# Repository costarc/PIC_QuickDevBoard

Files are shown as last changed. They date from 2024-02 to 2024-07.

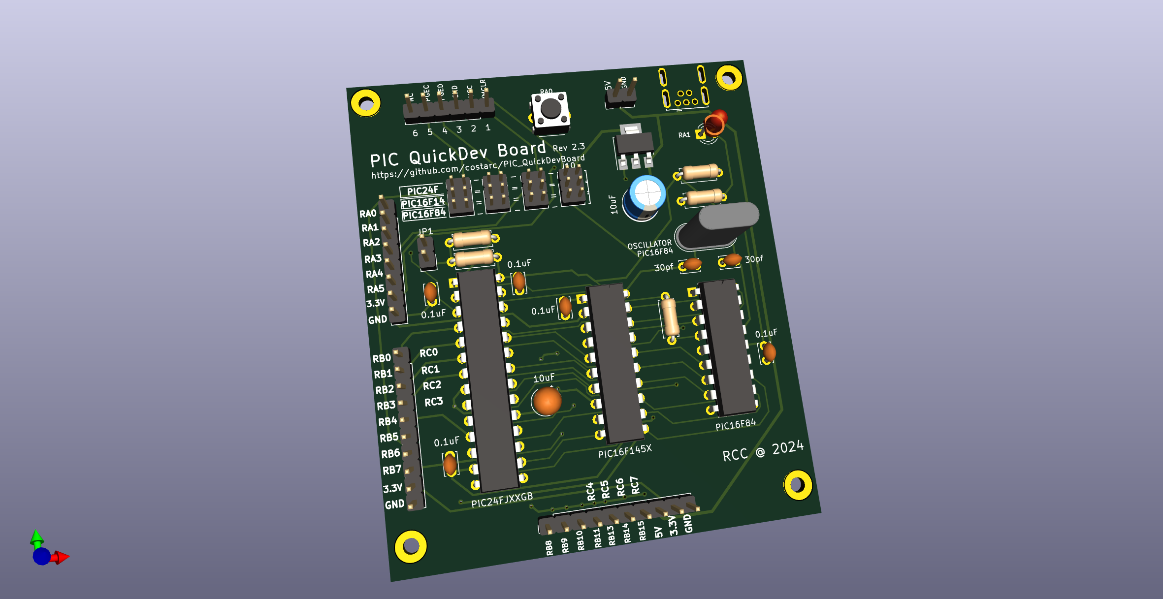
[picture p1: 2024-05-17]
PIC_QuickDevBoard2.png

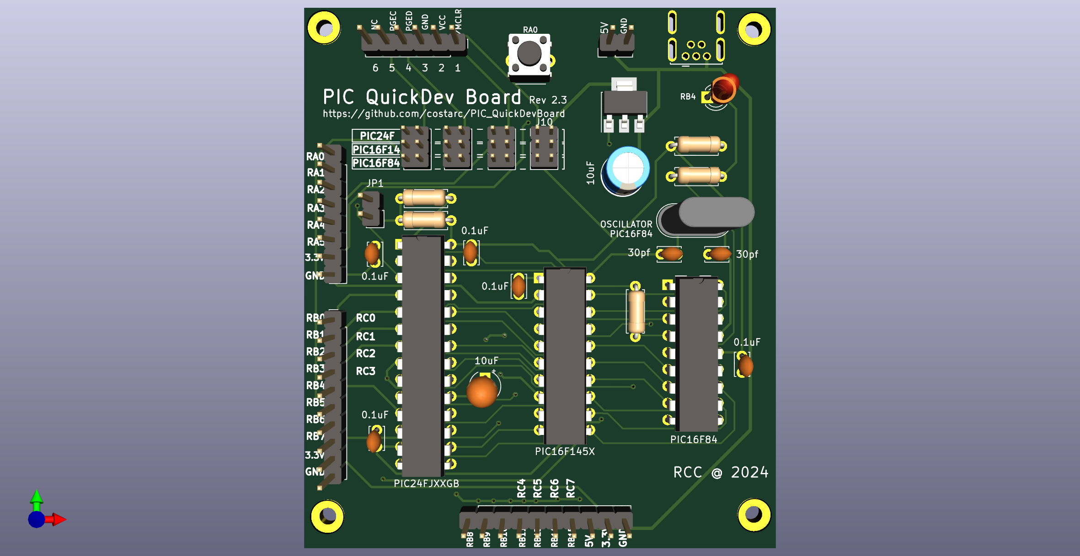
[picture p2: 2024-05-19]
PIC_QuickDevBoard.png

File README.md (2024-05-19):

# PIC_QuickDevBoard
Small and simple PIC16F &amp; PIC24F Development Board with Programming Support for PICKit

Rev 2.3
- Added demo project for all three suported PIC models
- Changed LED to PORT RB4 to be compatible with the 3 PICs supported by the board
- Added missing terminals in the mini-usb custom footprint
- Changed LED resistor from 270R to 470R to avoid led light too bright
- Changed PIC16F84 /MCLR pull-up resistor from 270R to 10K

Rev 2.2
- Adjustments to mini-usb footprint
- Fixed power rails to PC16F145X that was not allowing programming the microcontroller

Rev 2.1
- Updated footprint for USB-Micro to move it to the comopnent side (vcc - gnd was inverted)
- Fix for 5V PICs (16F) with addtion o extra jumpers
- Inverted PICKIT pin header for better alignment (cosmetic change)

Rev 2.0
- Initial production version

Fabrication
-----------
Measures: 70.90 x 81.30

Usage
-----

Power Requirements - PIC16
--------------------------

For correct programing, erasing and verifying the PIC, the external porwer must be provided via the USB connector or the PIN Header.

PIC16 requires 5V - if the PIN Header is used for power, 5V should be provided in this connector.
USB connector will provide the correct 5V for the PIC16.

Power Requirements - PIC24
--------------------------

For correct programing, erasing and verifying the PIC, the external porwer must be provided via the USB connector or the PIN Header.

PIC24 requires 3.3V - if the PIN Header is used for power, 3.3V must be provided in this connector - no conversion is done for voltages provided via this connector.
USB connector will provide the correct 3.3V for the PIC24 via coversion using the LD1117 converter in the board.

Operation * Programming
-----------------------

To develop & program A PIC device, set the three jumpers in position PIC24F, PIC16F14 OR PIC16F84 depending on which device you are being used.

To program the PIC24, remove jumper "Program". Re-insert after programming.

Development Resources
---------------------
All  I/O pins are exposed thorugh the Pin Headers in the board.
Additionaly, a Pushb Button and a LED are available for quick tests and experiments.
Push Button is connected to RA0
LED is connected to RB4

These components can be removed from the board if they are not needed or if they interfere with normal operation of these signals in the Pin Headers.

Default Demonstration Firmware
------------------------------
The demonstration firmware works the same for all models - the LED on RB4 will blink slowly, but if the push button is pressed it will blink faster.

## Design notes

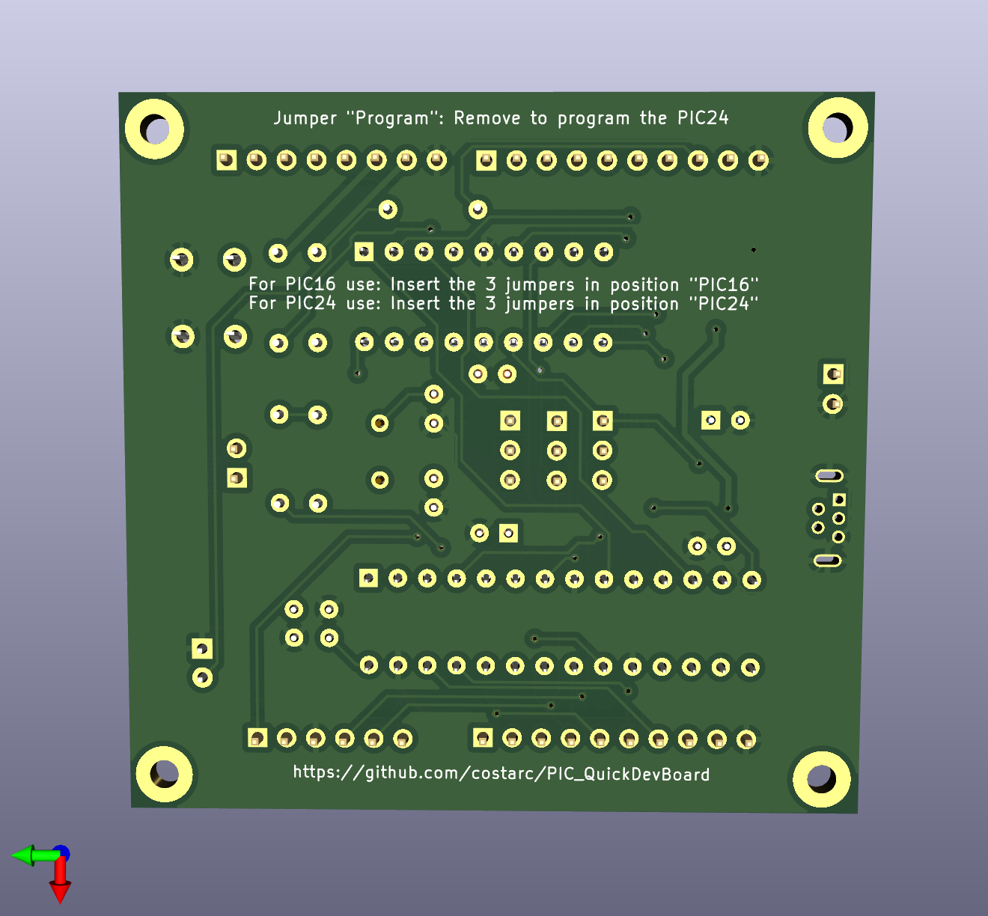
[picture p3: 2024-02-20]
PIC_QuickDevBoard_bside.png

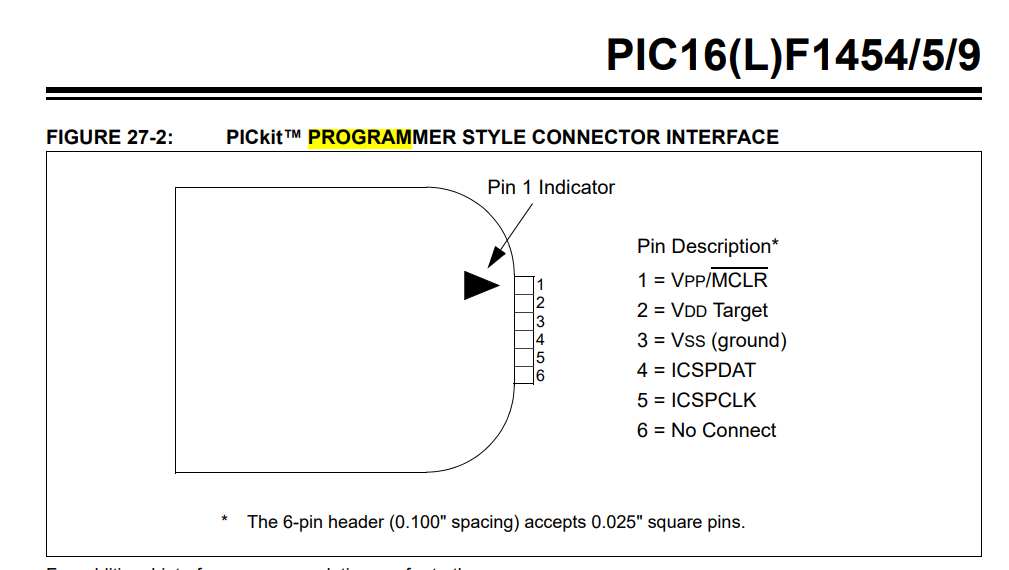
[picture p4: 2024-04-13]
Pickit Connection.png

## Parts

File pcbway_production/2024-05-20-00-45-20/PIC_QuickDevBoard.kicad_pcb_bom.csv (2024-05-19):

designator | quantity | value | pack | mpn | mount_type
C1, C2, C3, C8, C9 | 5 | 0.1uF | C_Disc_D3.4mm_W2.1mm_P2.50mm |  | tht
C4 | 1 | 10uF | CP_Radial_Tantal_D4.5mm_P2.50mm |  | tht
C5, C6 | 2 | 30pf | C_Disc_D3.4mm_W2.1mm_P2.50mm |  | tht
C7 | 1 | 10uF | CP_Radial_D6.3mm_P2.50mm |  | tht
D1 | 1 | LED | LED_D3.0mm |  | tht
H1, H2, H3, H4 | 4 | MountingHole | MountingHole_2.5mm_Pad |  | tht
J1 | 1 | Conn_01x08_Pin | PinHeader_1x08_P2.54mm_Vertical |  | tht
J10 | 1 | VCC Lines | PinHeader_2x03_P2.00mm_Vertical |  | tht
J2, J3 | 2 | Conn_01x08_Pin | PinHeader_1x10_P2.54mm_Vertical |  | tht
J4 | 1 | PowerSource | PinHeader_1x02_P2.54mm_Vertical |  | tht
J5 | 1 | PICKitConnector | PinHeader_1x06_P2.54mm_Vertical |  | tht
J6 | 1 | USB_B_Micro | USB_Mini-B_Tensility_4Holes |  | tht
J7 | 1 | PGEC_LINES | PinHeader_2x03_P2.00mm_Vertical |  | tht
J8 | 1 | PGED_LINES | PinHeader_2x03_P2.00mm_Vertical |  | tht
J9 | 1 | MCLR_LINES | PinHeader_2x03_P2.00mm_Vertical |  | tht
JP1 | 1 | Program | PinHeader_1x02_P2.54mm_Vertical |  | tht
R1 | 1 | 4.7K | R_Axial_DIN0207_L6.3mm_D2.5mm_P7.62mm_Horizontal |  | tht
R2 | 1 | 270 | R_Axial_DIN0207_L6.3mm_D2.5mm_P7.62mm_Horizontal |  | tht
R3, R5 | 2 | 10K | R_Axial_DIN0207_L6.3mm_D2.5mm_P7.62mm_Horizontal |  | tht
R4 | 1 | 470R | R_Axial_DIN0207_L6.3mm_D2.5mm_P7.62mm_Horizontal |  | tht
SW1 | 1 | SW_Push | SW_PUSH_6mm_2Holes |  | tht
U1 | 1 | PIC24F | DIP-28_W7.62mm |  | tht
U2 | 1 | PIC16F84 | DIP-18_W7.62mm |  | tht
U3 | 1 | LDA33A | SOT-223-3_TabPin2 |  | smt
U4 | 1 | PIC16F1459-IP | DIP-20_W7.62mm |  | tht
Y1 | 1 | Crystal | Crystal_HC49-U_Vertical |  | tht

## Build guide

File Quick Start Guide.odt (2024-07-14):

# PIC25FJ32GB002 (and similar / compatible devices)

Set the QuickDev Board jumpers in position “PIC24F”.

Plug the PIC in the socket.

Connect the PICKit TO QuickDev Board.

Open MPLAB IPE.

In Device option, select the PIC model.

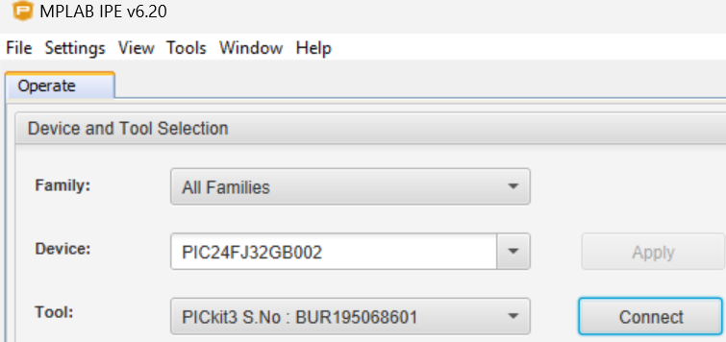
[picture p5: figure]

External power is not required to program this PIC - under Power Settings, enable PICKit to power the circuit.

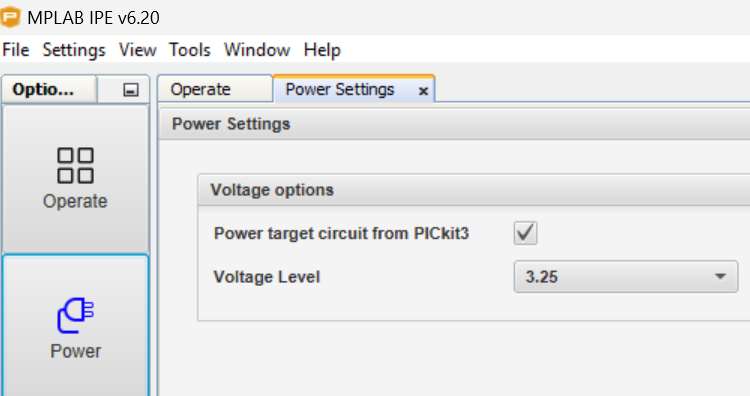
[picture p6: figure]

Connect.

Browse to the folder with the file to program into the PIC and load it

Program.

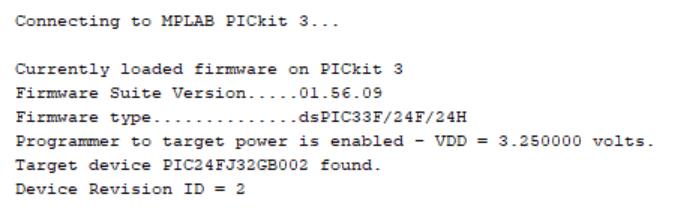
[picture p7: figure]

The demo program blinks LED in the QuickDev Board (PIN RB4), which is also available in the pin header .

The push button is connected to PIN RA0, when pressed will make the led blink faster.

# PIC16F1459 and PIC16F84

Set the QuickDev Board jumpers in position “PIC16F14” when programming PIC16F1454, PIC16F1455 or PIC16F1459.

Set the QuickDev Board jumpers in position “PIC16F84” when programming PIC16F84 or PIC16F84A.

These PIC will need external power supply connected to the board. Also disable the option to power the circuit in the MPLAB IPE.

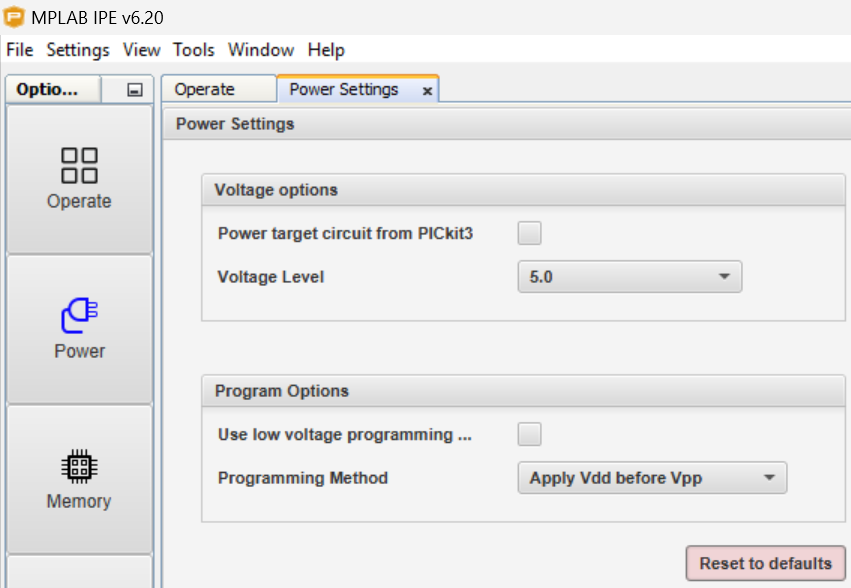
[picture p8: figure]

A successful connection to PIC16F1459 will display the following information.

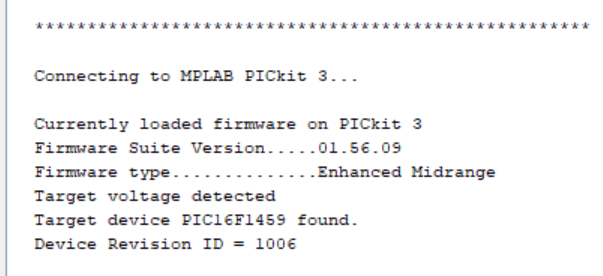
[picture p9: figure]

A successful connection to PIC16F84 will display the following information.

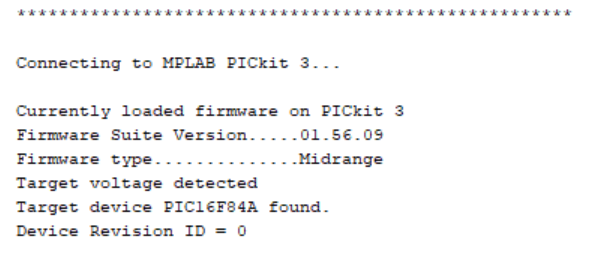
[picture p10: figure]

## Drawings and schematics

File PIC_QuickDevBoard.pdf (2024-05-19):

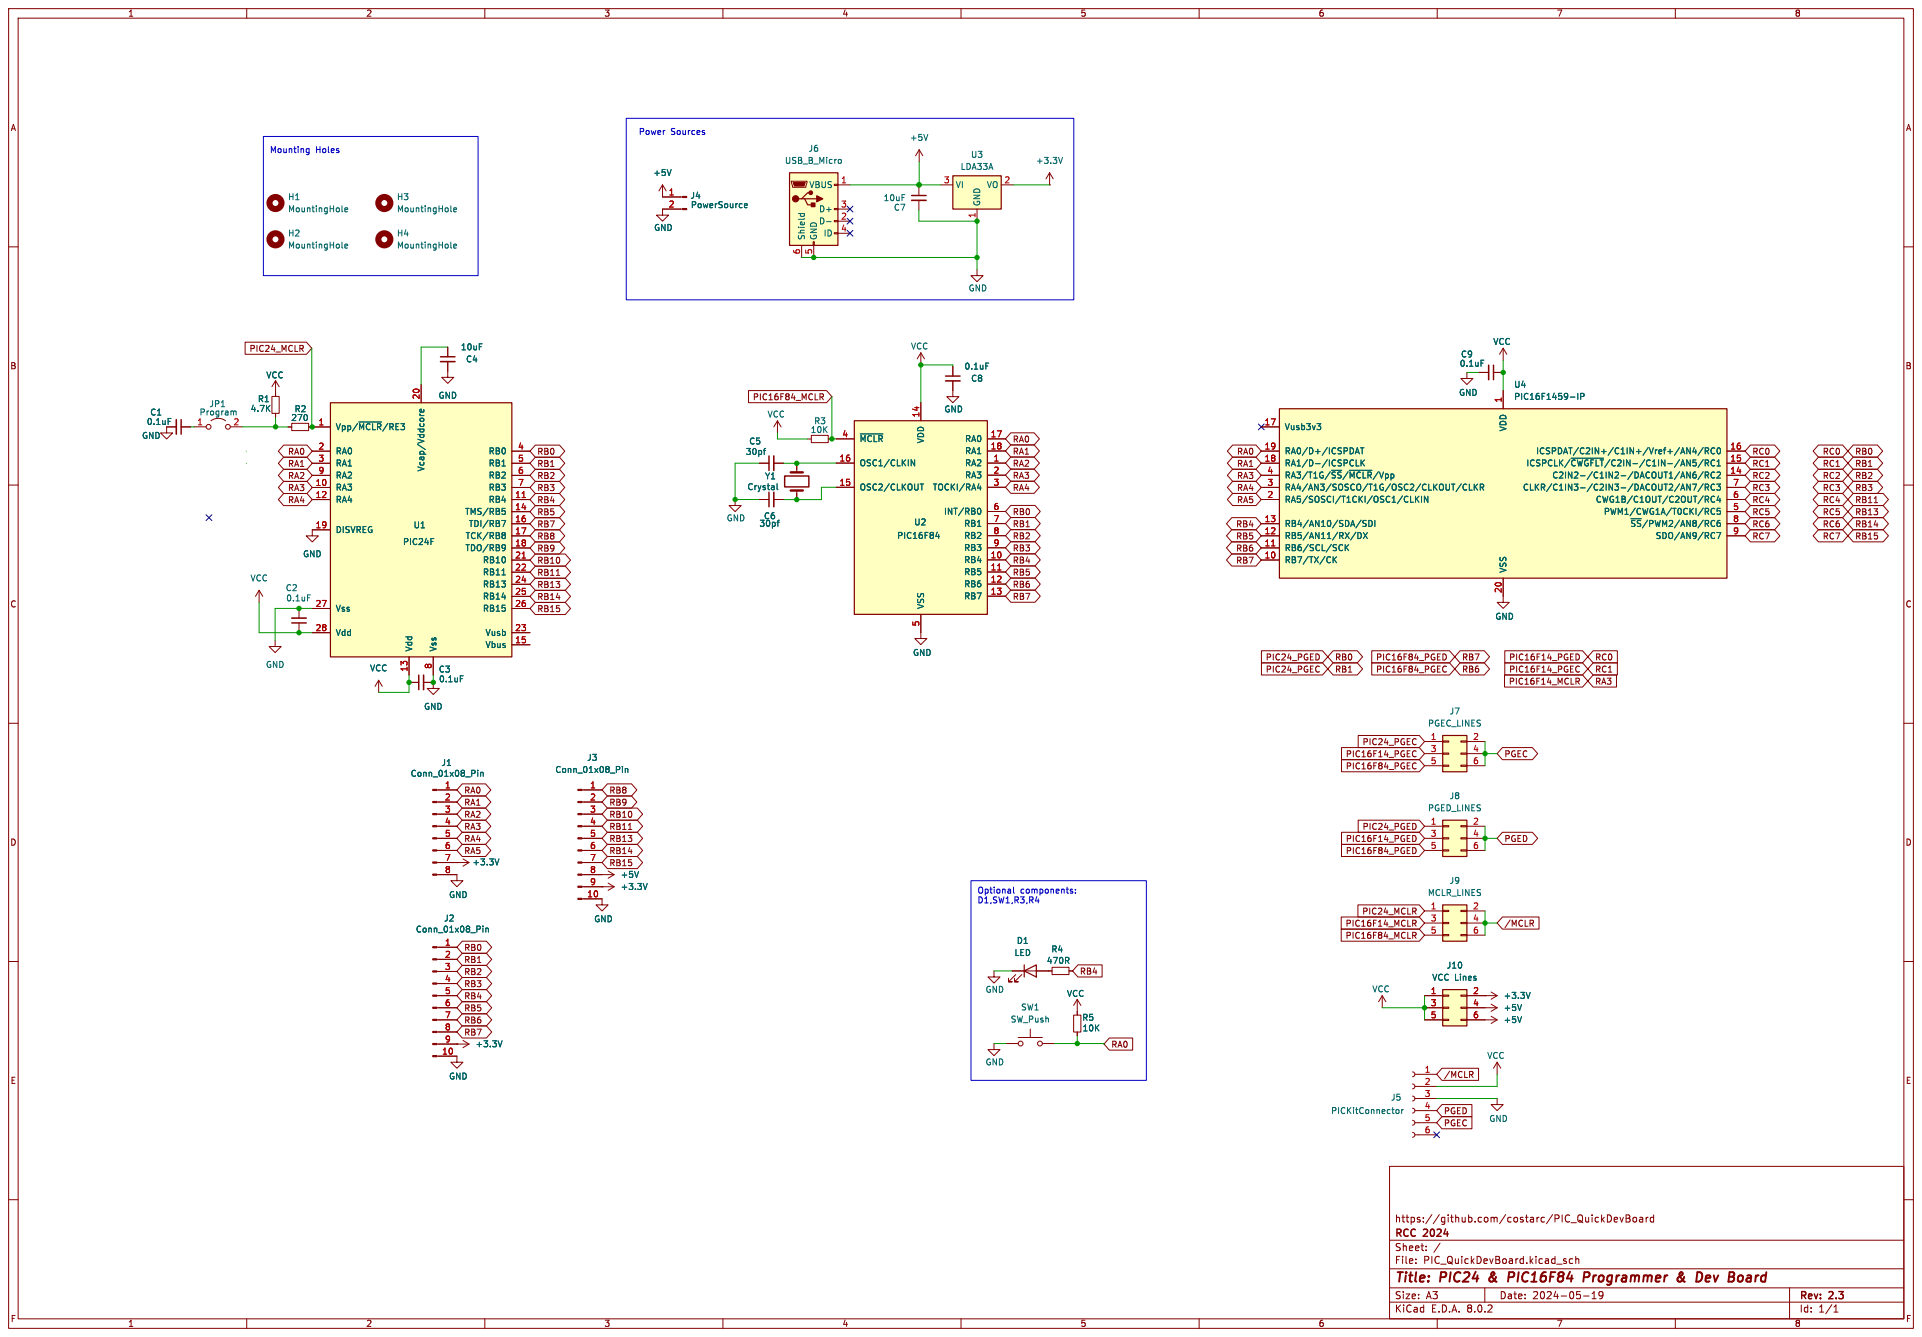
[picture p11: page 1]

1 RB7/TX/CK 10 RB6/SCL/SCK 11 RB5/AN11/RX/DX 12 RB4/AN10/SDA/SDI 13 C2IN2-/C1IN2-/DACOUT1/AN6/RC2

https://github.com/costarc/PIC_QuickDevBoard

Id: 1/1 Title: PIC24 & PIC16F84 Programmer & Dev Board

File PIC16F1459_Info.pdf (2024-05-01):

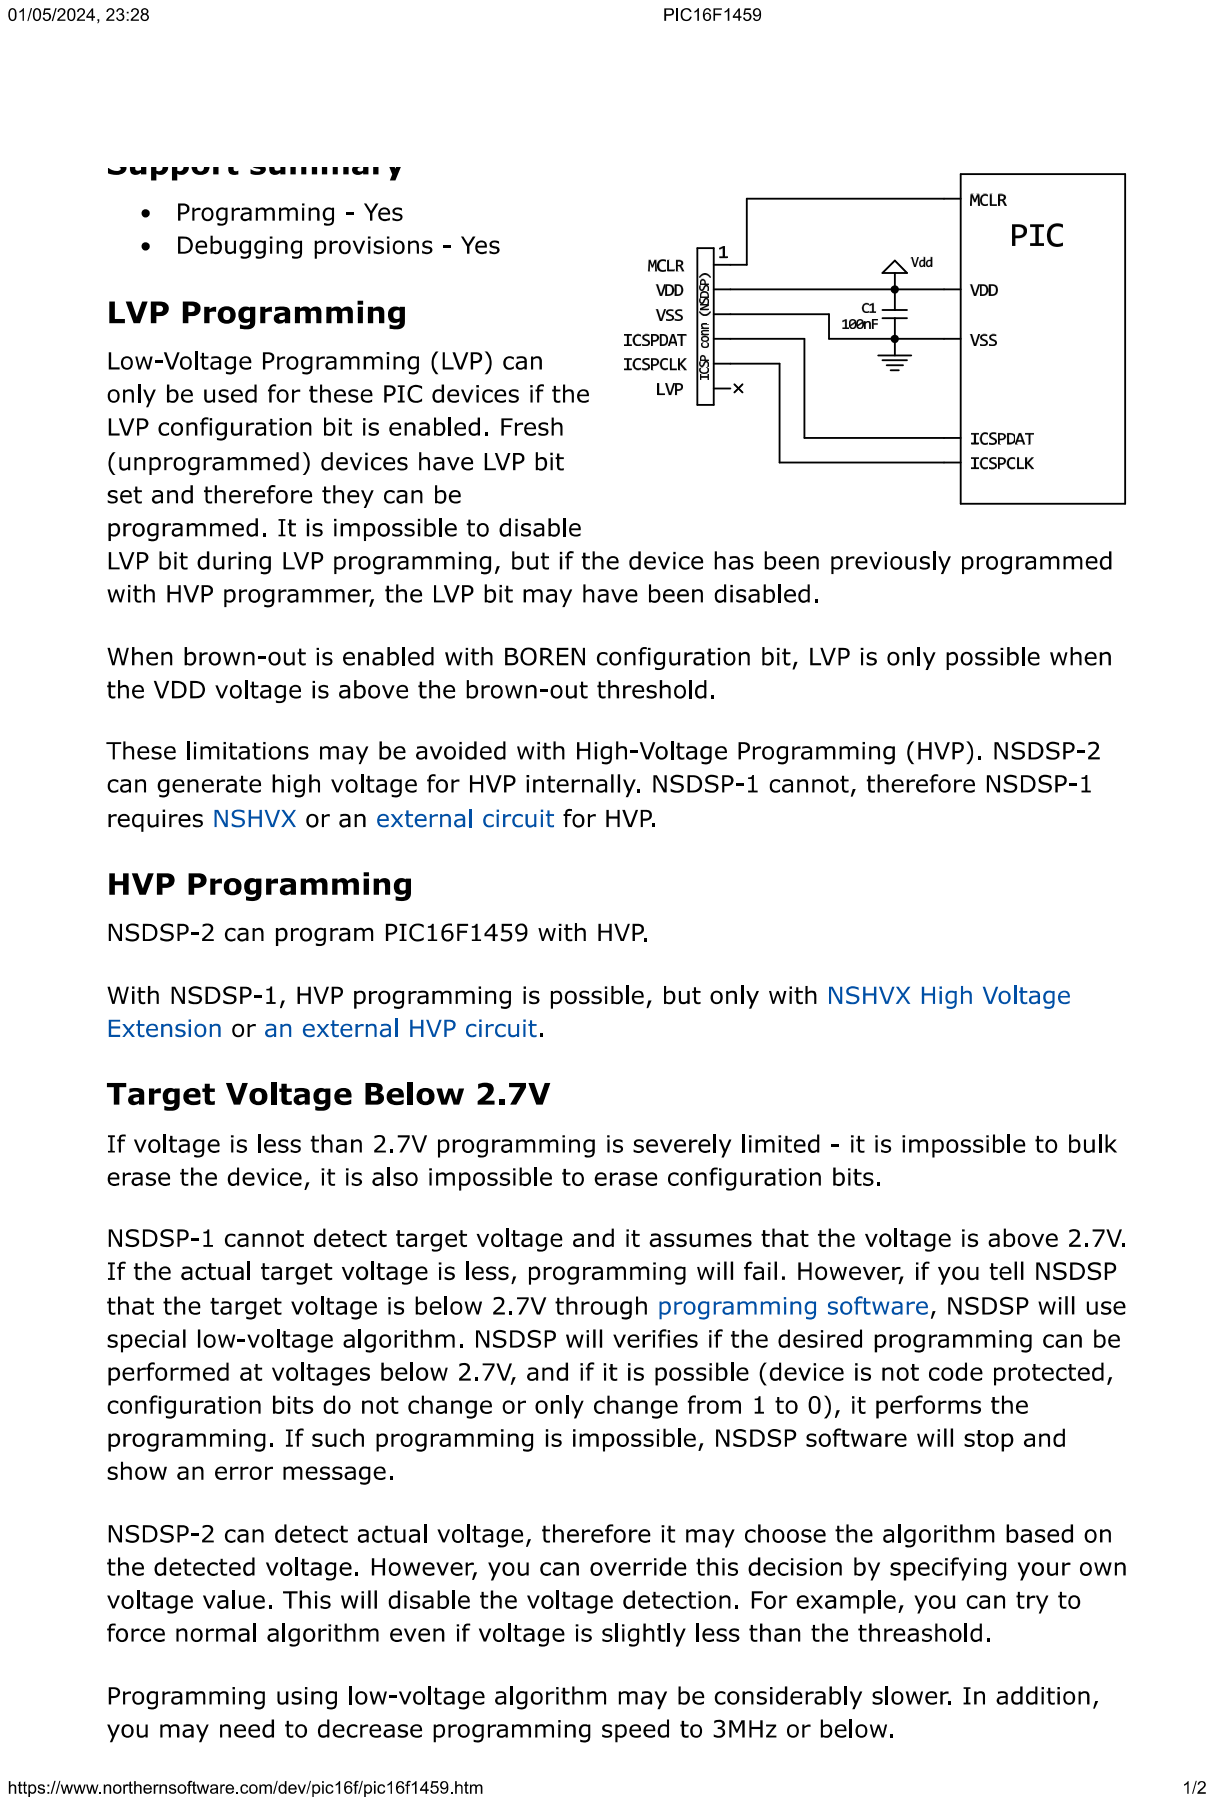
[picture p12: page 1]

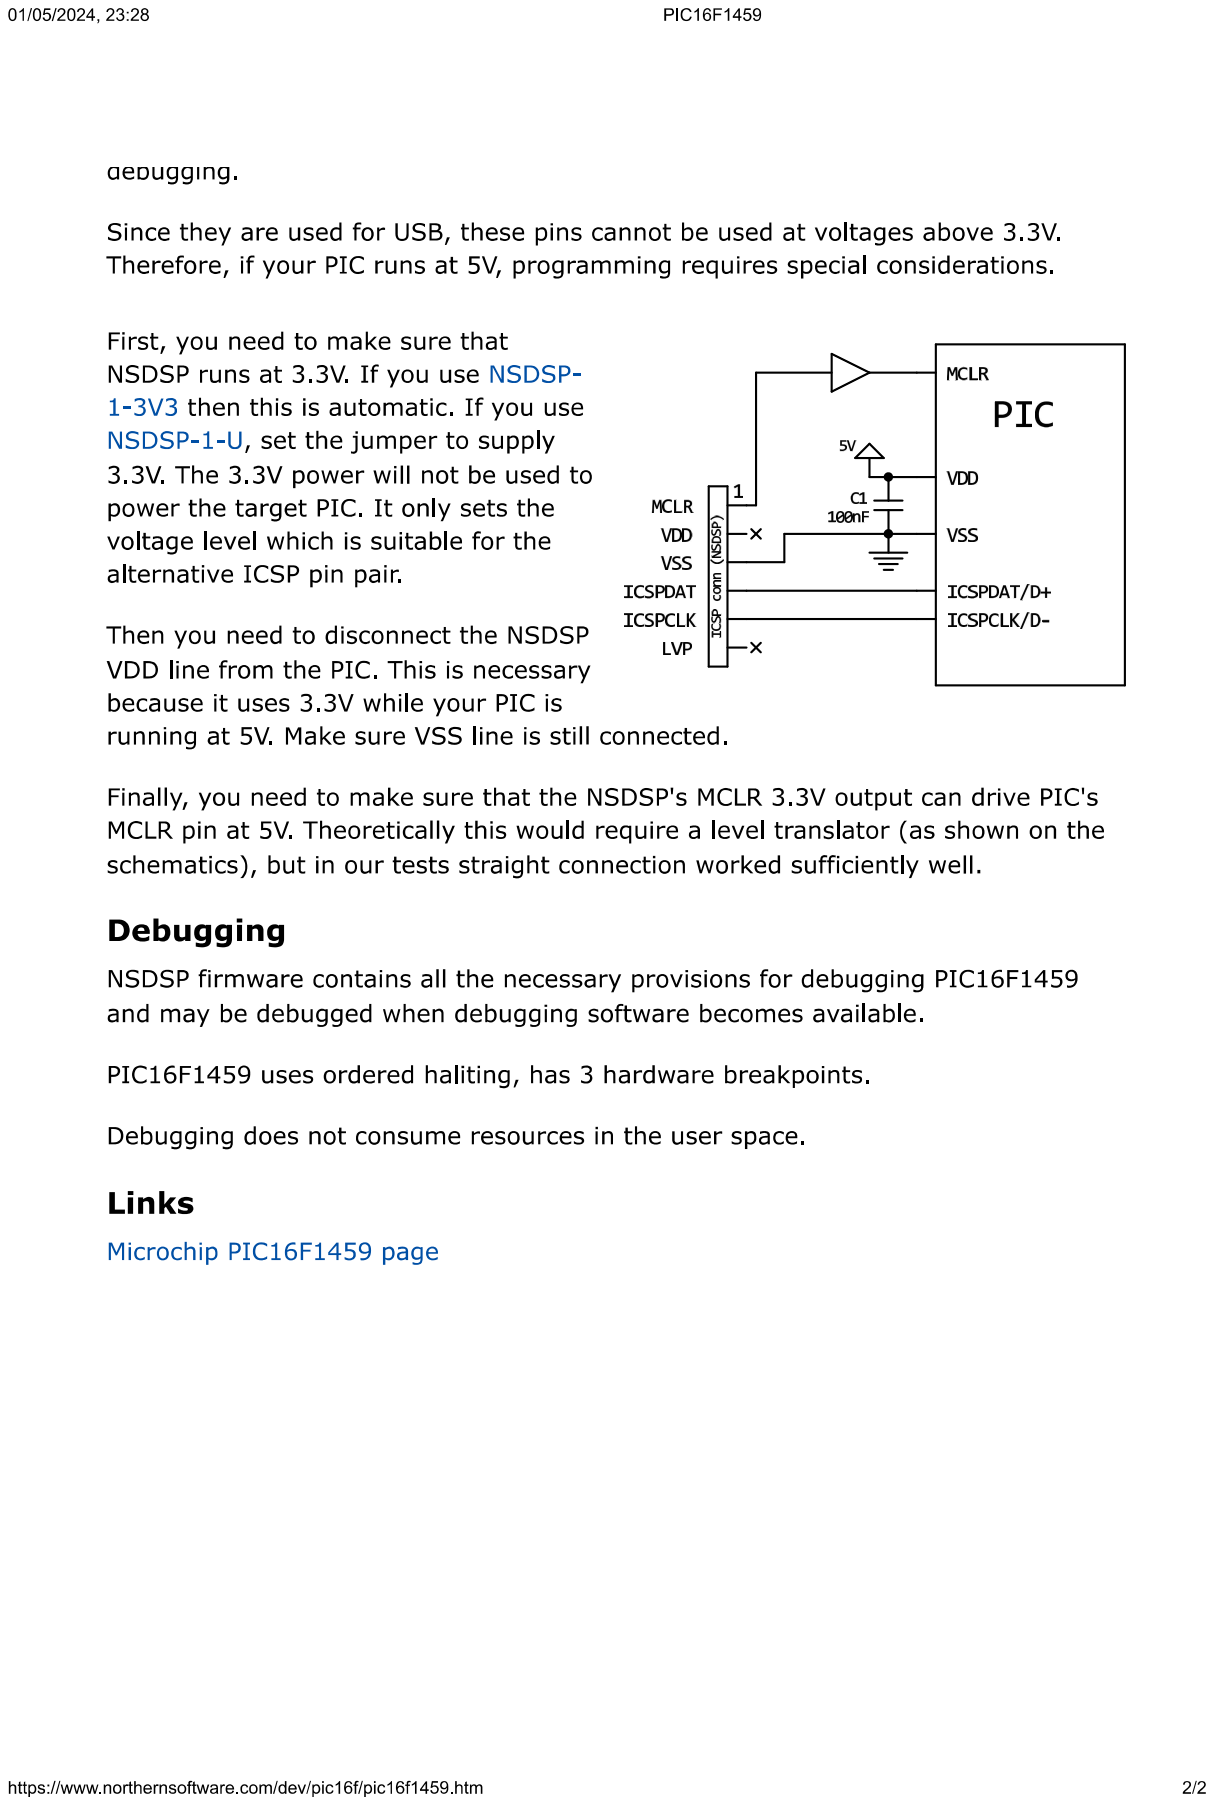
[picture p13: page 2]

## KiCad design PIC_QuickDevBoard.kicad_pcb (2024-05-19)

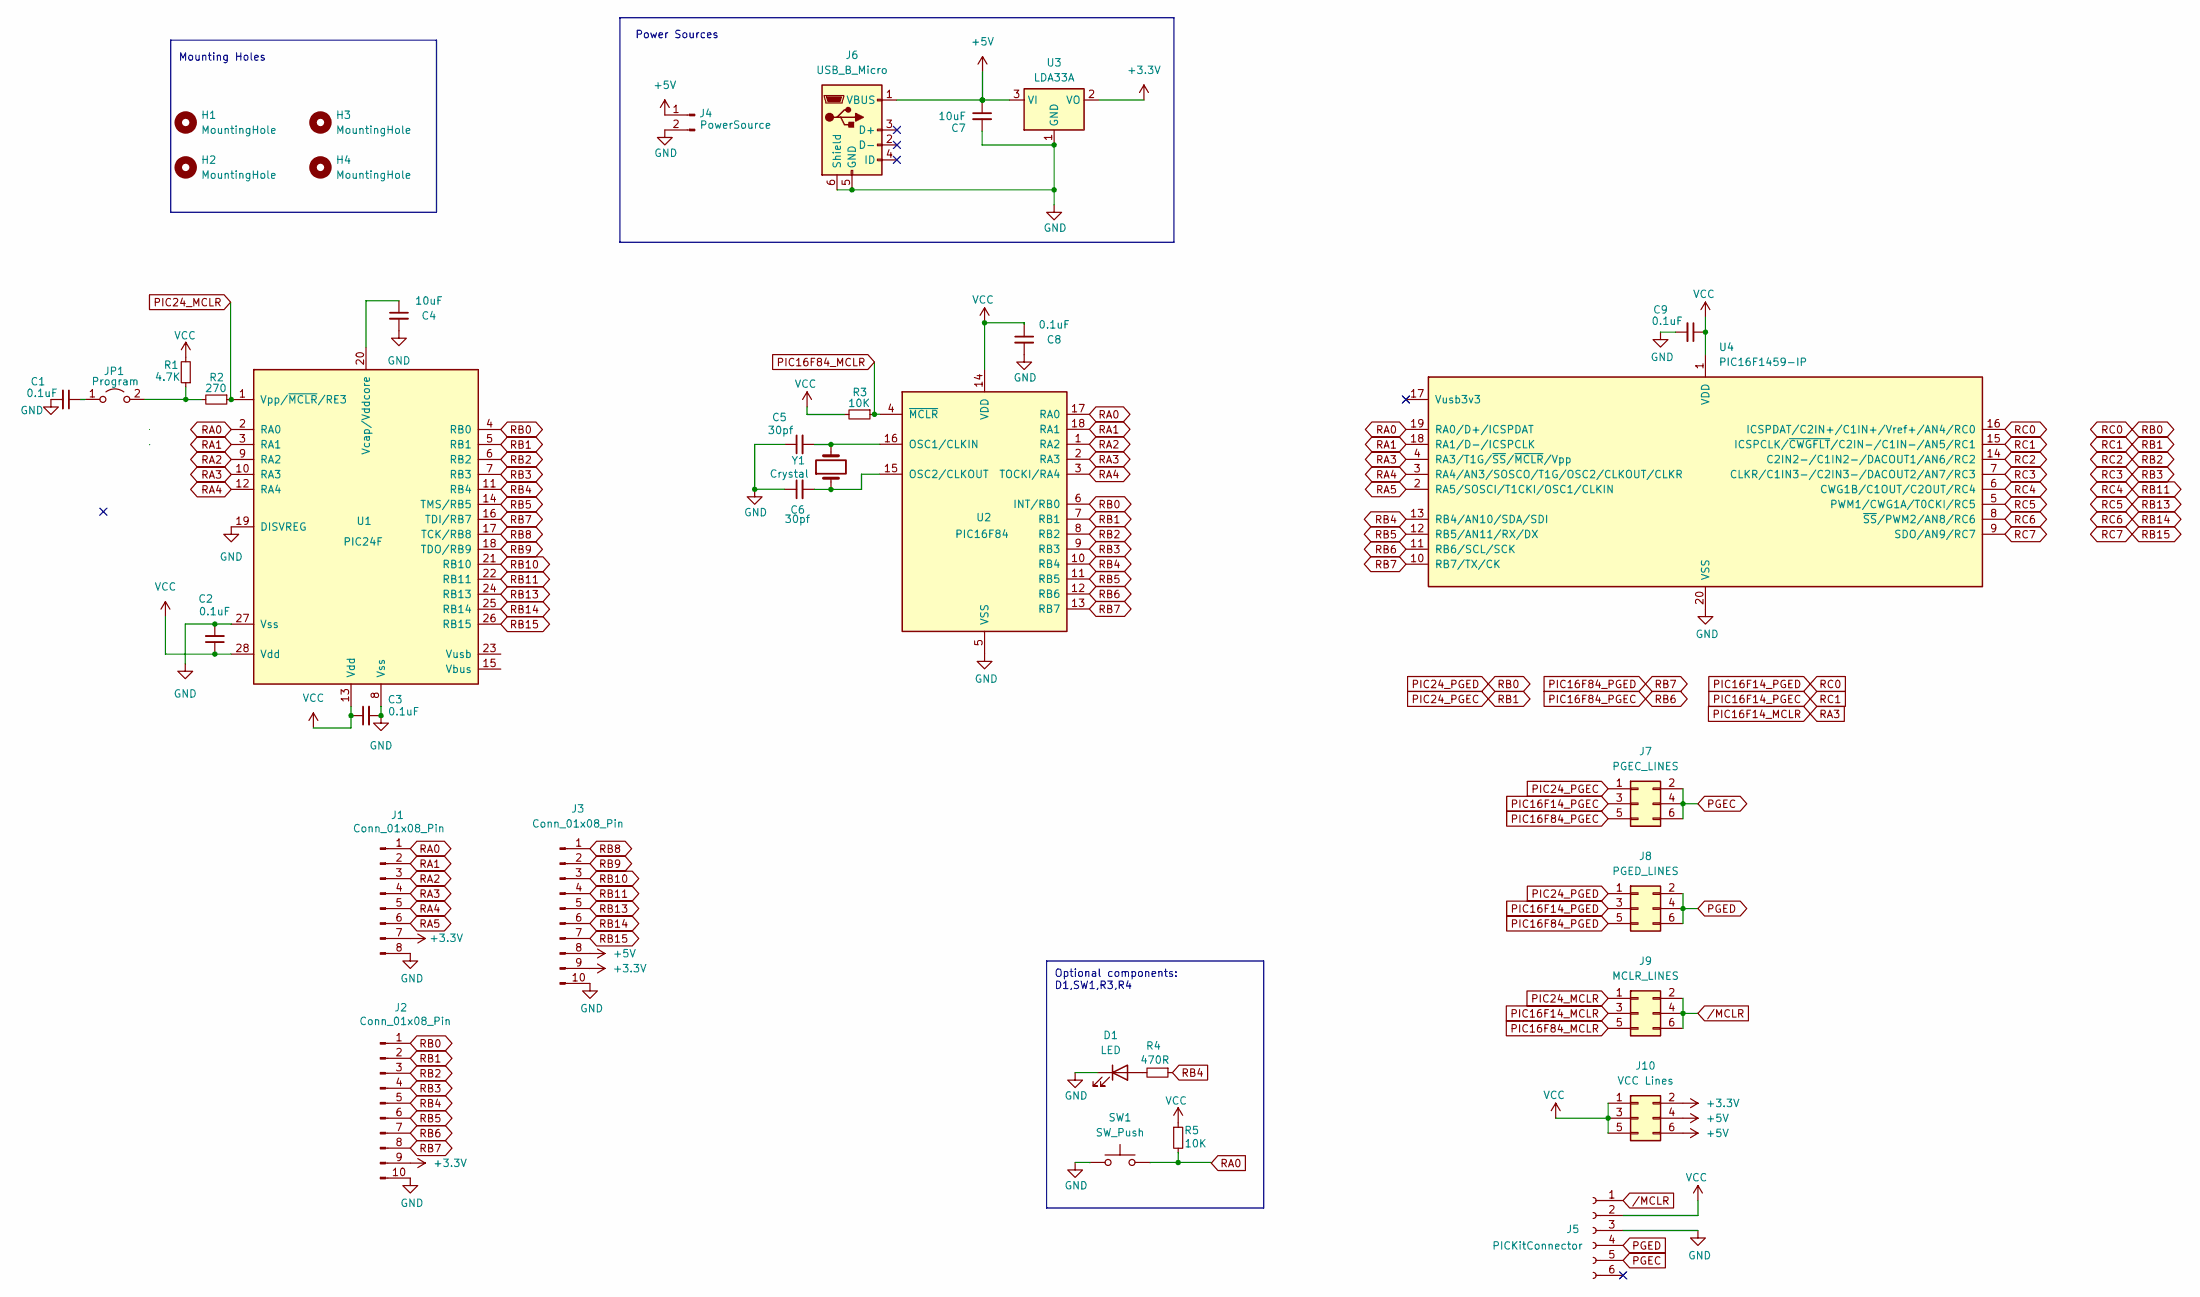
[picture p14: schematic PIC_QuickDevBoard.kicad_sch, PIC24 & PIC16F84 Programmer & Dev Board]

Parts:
C1, C2, C3, C8, C9: 0.1uF; C_Disc_D3.4mm_W2.1mm_P2.50mm
C4: 10uF; CP_Radial_Tantal_D4.5mm_P2.50mm
C5, C6: 30pf; C_Disc_D3.4mm_W2.1mm_P2.50mm
C7: 10uF; CP_Radial_D6.3mm_P2.50mm
D1: LED; LED_D3.0mm
H1, H2, H3, H4: MountingHole; MountingHole_2.5mm_Pad
J1: Conn_01x08_Pin; PinHeader_1x08_P2.54mm_Vertical
J2, J3: Conn_01x08_Pin; PinHeader_1x10_P2.54mm_Vertical
J4: PowerSource; PinHeader_1x02_P2.54mm_Vertical
J5: PICKitConnector; PinHeader_1x06_P2.54mm_Vertical
J6: USB_B_Micro; USB_Mini-B_Tensility_4Holes
J7: PGEC_LINES; PinHeader_2x03_P2.00mm_Vertical
J8: PGED_LINES; PinHeader_2x03_P2.00mm_Vertical
J9: MCLR_LINES; PinHeader_2x03_P2.00mm_Vertical
J10: VCC Lines; PinHeader_2x03_P2.00mm_Vertical
JP1: Program; PinHeader_1x02_P2.54mm_Vertical
R1: 4.7K; R_Axial_DIN0207_L6.3mm_D2.5mm_P7.62mm_Horizontal
R2: 270; R_Axial_DIN0207_L6.3mm_D2.5mm_P7.62mm_Horizontal
R3, R5: 10K; R_Axial_DIN0207_L6.3mm_D2.5mm_P7.62mm_Horizontal
R4: 470R; R_Axial_DIN0207_L6.3mm_D2.5mm_P7.62mm_Horizontal
SW1: SW_Push; SW_PUSH_6mm_2Holes
U1: PIC24F; DIP-28_W7.62mm
U2: PIC16F84; DIP-18_W7.62mm
U3: LDA33A; SOT-223-3_TabPin2
U4: PIC16F1459-IP; DIP-20_W7.62mm
Y1: Crystal; Crystal_HC49-U_Vertical

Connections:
+3.3V: J1.7, J2.9, J3.9, J10.2, U3.2 (VO)
+5V: C7.1, J3.8, J4.1, J6.1 (VBUS), J10.4, J10.6, U3.3 (VI)
GND: C1.2, C2.2, C3.2, C4.2, C5.1, C6.1, C7.2, C8.2, C9.2, D1.1 (K), J1.8, J2.10, J3.10, J4.2, J5.3, J6.5 (GND), J6.6 (Shield), SW1.1, U1.8 (Vss), U1.19 (DISVREG), U1.27 (Vss), U2.5 (VSS), U3.1 (GND), U4.20 (VSS)
unnamed: D1.2 (A), R4.2
unnamed: C1.1, JP1.1 (A)
unnamed: JP1.2 (B), R1.1, R2.2
unnamed: C4.1, U1.20 (Vcap/Vddcore)
unnamed: C5.2, U2.16 (OSC1/CLKIN), Y1.2
unnamed: C6.2, U2.15 (OSC2/CLKOUT), Y1.1
PGEC: J5.5, J7.2, J7.4, J7.6
PGED: J5.4, J8.2, J8.4, J8.6
PIC16F14_MCLR: J1.4, J9.3, U1.10 (RA3), U2.2 (RA3), U4.4 (RA3/T1G/~SS/~MCLR/Vpp)
PIC16F14_PGEC: J2.2, J7.1, J7.3, U1.5 (RB1), U2.7 (RB1), U4.15 (ICSPCLK/~CWGFLT/C2IN-/C1IN-/AN5/RC1)
PIC16F14_PGED: J2.1, J8.1, J8.3, U1.4 (RB0), U2.6 (INT/RB0), U4.16 (ICSPDAT/C2IN+/C1IN+/Vref+/AN4/RC0)
PIC16F84_MCLR: J9.5, R3.1, U2.4 (~MCLR)
PIC16F84_PGEC: J2.7, J7.5, U2.12 (RB6), U4.11 (RB6/SCL/SCK)
PIC16F84_PGED: J2.8, J8.5, U1.16 (TDI/RB7), U2.13 (RB7), U4.10 (RB7/TX/CK)
PIC24_MCLR: J9.1, R2.1, U1.1 (Vpp/~MCLR/RE3)
RA0: J1.1, R5.2, SW1.2, U1.2 (RA0), U2.17 (RA0), U4.19 (RA0/D+/ICSPDAT)
RA1: J1.2, U1.3 (RA1), U2.18 (RA1), U4.18 (RA1/D-/ICSPCLK)
RA2: J1.3, U1.9 (RA2), U2.1 (RA2)
RA4: J1.5, U1.12 (RA4), U2.3 (TOCKI/RA4), U4.3 (RA4/AN3/SOSCO/T1G/OSC2/CLKOUT/CLKR)
RA5: J1.6, U4.2 (RA5/SOSCI/T1CKI/OSC1/CLKIN)
RB2: J2.3, U1.6 (RB2), U2.8 (RB2), U4.14 (C2IN2-/C1IN2-/DACOUT1/AN6/RC2)
RB3: J2.4, U1.7 (RB3), U2.9 (RB3), U4.7 (CLKR/C1IN3-/C2IN3-/DACOUT2/AN7/RC3)
RB4: J2.5, R4.1, U1.11 (RB4), U2.10 (RB4), U4.13 (RB4/AN10/SDA/SDI)
RB5: J2.6, U1.14 (TMS/RB5), U2.11 (RB5), U4.12 (RB5/AN11/RX/DX)
RB8: J3.1, U1.17 (TCK/RB8)
RB9: J3.2, U1.18 (TDO/RB9)
RB10: J3.3, U1.21 (RB10)
RB11: J3.4, U1.22 (RB11), U4.6 (CWG1B/C1OUT/C2OUT/RC4)
RB13: J3.5, U1.24 (RB13), U4.5 (PWM1/CWG1A/T0CKI/RC5)
RB14: J3.6, U1.25 (RB14), U4.8 (~SS/PWM2/AN8/RC6)
RB15: J3.7, U1.26 (RB15), U4.9 (SDO/AN9/RC7)
VCC: C2.1, C3.1, C8.1, C9.1, J5.2, J10.1, J10.3, J10.5, R1.2, R3.2, R5.1, U1.13 (Vdd), U1.28 (Vdd), U2.14 (VDD), U4.1 (VDD)
/MCLR: J5.1, J9.2, J9.4, J9.6

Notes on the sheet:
Optional components: D1,SW1,R3,R4
Mounting Holes
Power Sources

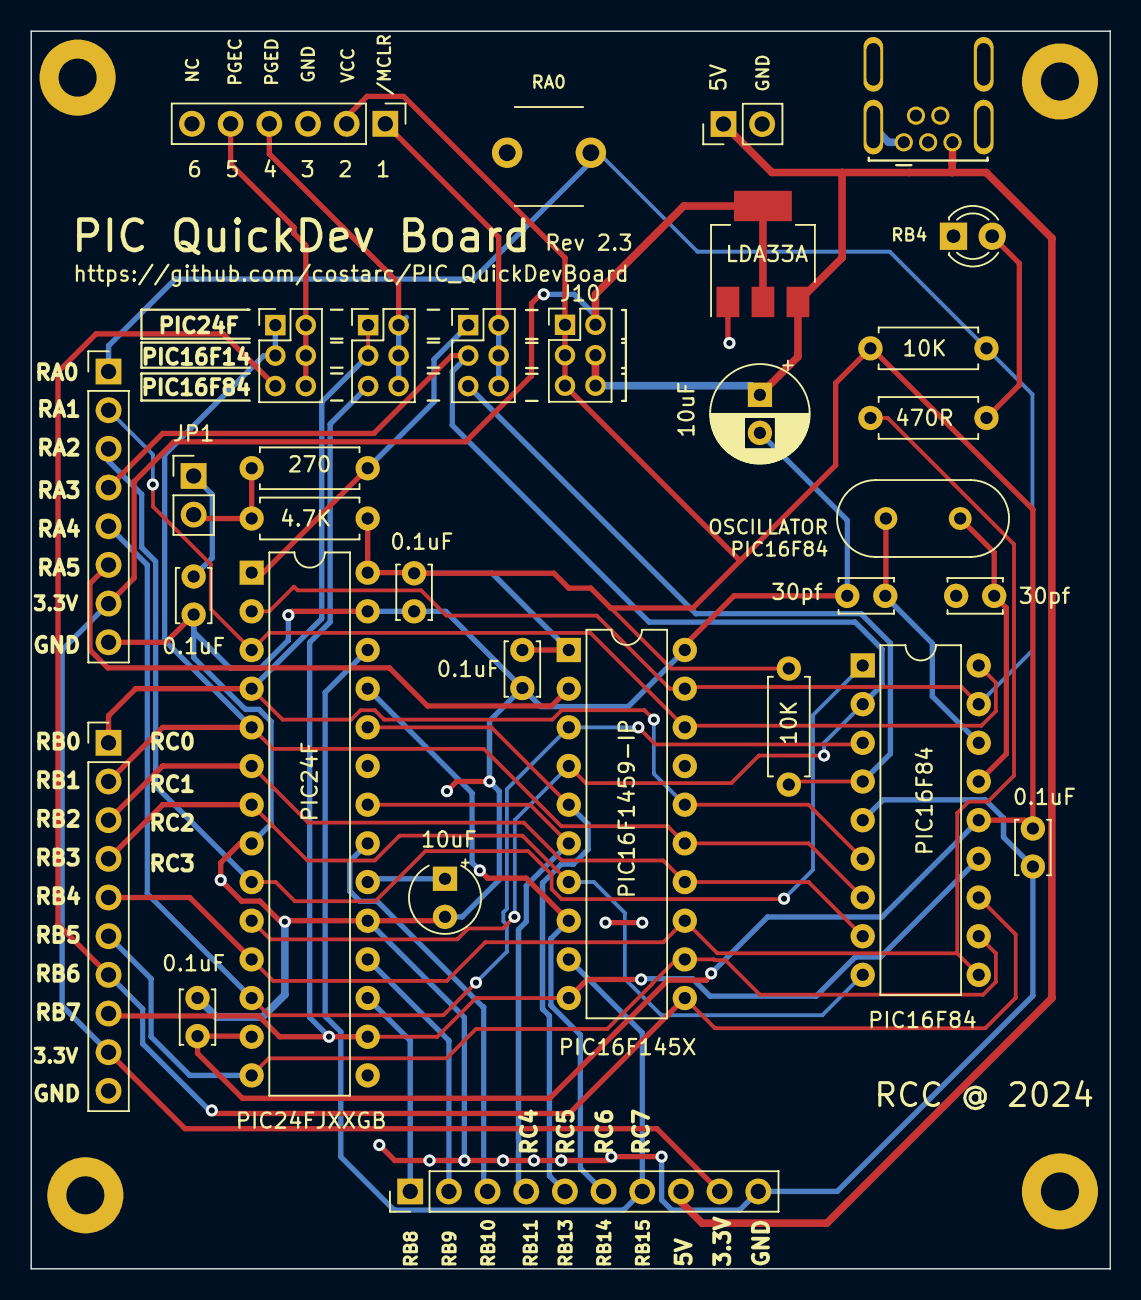
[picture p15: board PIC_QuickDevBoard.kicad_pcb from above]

Board: 2 copper layers, 70.9 x 81.3 mm, 36 parts (0 on the bottom side), 36 nets.

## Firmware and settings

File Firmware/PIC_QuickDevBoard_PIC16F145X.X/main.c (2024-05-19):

/*
MIT License

Copyright (c) 2024 Ronivon Costa

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
THE SOFTWARE IS PROVIDED "AS IS", WITHOUT WARRANTY OF ANY KIND, EXPRESS OR
IMPLIED, INCLUDING BUT NOT LIMITED TO THE WARRANTIES OF MERCHANTABILITY,
FITNESS FOR A PARTICULAR PURPOSE AND NONINFRINGEMENT. IN NO EVENT SHALL THE
AUTHORS OR COPYRIGHT HOLDERS BE LIABLE FOR ANY CLAIM, DAMAGES OR OTHER
LIABILITY, WHETHER IN AN ACTION OF CONTRACT, TORT OR OTHERWISE, ARISING FROM,
OUT OF OR IN CONNECTION WITH THE SOFTWARE OR THE USE OR OTHER DEALINGS IN THE
SOFTWARE.
*/

#include "mcc_generated_files/system/system.h"
#include <stdio.h>

int hour = 0;
int minute = 0;
int second = 0;
int ms = 0;

void Timer_CallBack_Function(void) {
    ms++;
    if (ms == 1000) {
        ms = 0;
        second++;
        if (second == 60) {
            second = 0;
            minute++;
            if (minute == 60) {
                minute = 0;
                hour++;
                if (hour == 24) {
                    hour = 0;
                }
            }
        }
        printf("%d:%d:%d\n",hour,minute,second);
        IO_RB7_Toggle();
    }
}

/*
    Main application
*/

int main(void)
{
    printf("--> Starting ...\n");
    SYSTEM_Initialize();
    Timer0_Initialize();
    INTERRUPT_GlobalInterruptEnable();
    INTERRUPT_PeripheralInterruptEnable();
    Timer0_OverflowCallbackRegister(Timer_CallBack_Function);
    
    while(1)
    {  

    RB4 = 1;
    if (BUTTON_GetValue() == 0)
        __delay_ms(100);
    else
        __delay_ms(500);
    RB4 = 0;
    if (BUTTON_GetValue() == 0)
        __delay_ms(100);
    else
        __delay_ms(500);
    }    
}

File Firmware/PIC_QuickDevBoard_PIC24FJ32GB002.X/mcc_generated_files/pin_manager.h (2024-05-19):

/**
  PIN MANAGER Generated Driver File

  @Company:
    Microchip Technology Inc.

  @File Name:
    pin_manager.h

  @Summary:
    This is the generated manager file for the PIC24 / dsPIC33 / PIC32MM MCUs device.  This manager
    configures the pins direction, initial state, analog setting.
    The peripheral pin select, PPS, configuration is also handled by this manager.

  @Description:
    This source file provides implementations for PIN MANAGER.
    Generation Information :
        Product Revision  :  PIC24 / dsPIC33 / PIC32MM MCUs - 1.171.4
        Device            :  PIC24FJ32GB002
    The generated drivers are tested against the following:
        Compiler          :  XC16 v2.10
        MPLAB 	          :  MPLAB X v6.05
*/

/*
    (c) 2020 Microchip Technology Inc. and its subsidiaries. You may use this
    software and any derivatives exclusively with Microchip products.

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
    IN NO EVENT WILL MICROCHIP BE LIABLE FOR ANY INDIRECT, SPECIAL, PUNITIVE,
    INCIDENTAL OR CONSEQUENTIAL LOSS, DAMAGE, COST OR EXPENSE OF ANY KIND
    WHATSOEVER RELATED TO THE SOFTWARE, HOWEVER CAUSED, EVEN IF MICROCHIP HAS
    BEEN ADVISED OF THE POSSIBILITY OR THE DAMAGES ARE FORESEEABLE. TO THE
    FULLEST EXTENT ALLOWED BY LAW, MICROCHIP'S TOTAL LIABILITY ON ALL CLAIMS IN
    ANY WAY RELATED TO THIS SOFTWARE WILL NOT EXCEED THE AMOUNT OF FEES, IF ANY,
    THAT YOU HAVE PAID DIRECTLY TO MICROCHIP FOR THIS SOFTWARE.

    MICROCHIP PROVIDES THIS SOFTWARE CONDITIONALLY UPON YOUR ACCEPTANCE OF THESE
    TERMS.
*/

#ifndef _PIN_MANAGER_H
#define _PIN_MANAGER_H
/**
    Section: Includes
*/
#include <xc.h>

/**
    Section: Device Pin Macros
*/
/**
  @Summary
    Sets the GPIO pin, RA0, high using LATA0.

  @Description
    Sets the GPIO pin, RA0, high using LATA0.

  @Preconditions
    The RA0 must be set to an output.

  @Returns
    None.

  @Param
    None.

  @Example
    <code>
    // Set RA0 high (1)
    BUTTON_SetHigh();
    </code>

*/
#define BUTTON_SetHigh()          (_LATA0 = 1)
/**
  @Summary
    Sets the GPIO pin, RA0, low using LATA0.

  @Description
    Sets the GPIO pin, RA0, low using LATA0.

  @Preconditions
    The RA0 must be set to an output.

  @Returns
    None.

  @Param
    None.

  @Example
    <code>
    // Set RA0 low (0)
    BUTTON_SetLow();
    </code>

*/
#define BUTTON_SetLow()           (_LATA0 = 0)
/**
  @Summary
    Toggles the GPIO pin, RA0, using LATA0.

  @Description
    Toggles the GPIO pin, RA0, using LATA0.

  @Preconditions
    The RA0 must be set to an output.

  @Returns
    None.

  @Param
    None.

  @Example
    <code>
    // Toggle RA0
    BUTTON_Toggle();
    </code>

*/
#define BUTTON_Toggle()           (_LATA0 ^= 1)
/**
  @Summary
    Reads the value of the GPIO pin, RA0.

  @Description
    Reads the value of the GPIO pin, RA0.

  @Preconditions
    None.

  @Returns
    None.

  @Param
    None.

  @Example
    <code>
    uint16_t portValue;

    // Read RA0
    postValue = BUTTON_GetValue();
    </code>

*/
#define BUTTON_GetValue()         _RA0
/**
  @Summary
    Configures the GPIO pin, RA0, as an input.

  @Description
    Configures the GPIO pin, RA0, as an input.

  @Preconditions
    None.

  @Returns
    None.

  @Param
    None.

  @Example
    <code>
    // Sets the RA0 as an input
    BUTTON_SetDigitalInput();
    </code>

*/
#define BUTTON_SetDigitalInput()  (_TRISA0 = 1)
/**
  @Summary
    Configures the GPIO pin, RA0, as an output.

  @Description
    Configures the GPIO pin, RA0, as an output.

  @Preconditions
    None.

  @Returns
    None.

  @Param
    None.

  @Example
    <code>
    // Sets the RA0 as an output
    BUTTON_SetDigitalOutput();
    </code>

*/
#define BUTTON_SetDigitalOutput() (_TRISA0 = 0)
/**
  @Summary
    Sets the GPIO pin, RA1, high using LATA1.

  @Description
    Sets the GPIO pin, RA1, high using LATA1.

  @Preconditions
    The RA1 must be set to an output.

  @Returns
    None.

  @Param
    None.

  @Example
    <code>
    // Set RA1 high (1)
    IO_RA1_SetHigh();
    </code>

*/
#define IO_RA1_SetHigh()          (_LATA1 = 1)
/**
  @Summary
    Sets the GPIO pin, RA1, low using LATA1.

  @Description
    Sets the GPIO pin, RA1, low using LATA1.

  @Preconditions
    The RA1 must be set to an output.

  @Returns
    None.

  @Param
    None.

  @Example
    <code>
    // Set RA1 low (0)
    IO_RA1_SetLow();
    </code>

*/
#define IO_RA1_SetLow()           (_LATA1 = 0)
/**
  @Summary
    Toggles the GPIO pin, RA1, using LATA1.

  @Description
    Toggles the GPIO pin, RA1, using LATA1.

  @Preconditions
    The RA1 must be set to an output.

  @Returns
    None.

  @Param
    None.

  @Example
    <code>
    // Toggle RA1
    IO_RA1_Toggle();
    </code>

*/
#define IO_RA1_Toggle()           (_LATA1 ^= 1)
/**
  @Summary
    Reads the value of the GPIO pin, RA1.

  @Description
    Reads the value of the GPIO pin, RA1.

  @Preconditions
    None.

  @Returns
    None.

  @Param
    None.

  @Example
    <code>
    uint16_t portValue;

    // Read RA1
    postValue = IO_RA1_GetValue();
    </code>

*/
#define IO_RA1_GetValue()         _RA1
/**
  @Summary
    Configures the GPIO pin, RA1, as an input.

  @Description
    Configures the GPIO pin, RA1, as an input.

  @Preconditions
    None.

  @Returns
    None.

  @Param
    None.

  @Example
    <code>
    // Sets the RA1 as an input
    IO_RA1_SetDigitalInput();
    </code>

*/
#define IO_RA1_SetDigitalInput()  (_TRISA1 = 1)
/**
  @Summary
    Configures the GPIO pin, RA1, as an output.

  @Description
    Configures the GPIO pin, RA1, as an output.

  @Preconditions
    None.

  @Returns
    None.

  @Param
    None.

  @Example
    <code>
    // Sets the RA1 as an output
    IO_RA1_SetDigitalOutput();
    </code>

*/
#define IO_RA1_SetDigitalOutput() (_TRISA1 = 0)
/**
  @Summary
    Sets the GPIO pin, RA2, high using LATA2.

  @Description
    Sets the GPIO pin, RA2, high using LATA2.

  @Preconditions
    The RA2 must be set to an output.

  @Returns
    None.

  @Param
    None.

  @Example
    <code>
    // Set RA2 high (1)
    IO_RA2_SetHigh();
    </code>

*/
#define IO_RA2_SetHigh()          (_LATA2 = 1)
/**
  @Summary
    Sets the GPIO pin, RA2, low using LATA2.

  @Description
    Sets the GPIO pin, RA2, low using LATA2.

  @Preconditions
    The RA2 must be set to an output.

  @Returns
    None.

  @Param
    None.

  @Example
    <code>
    // Set RA2 low (0)
    IO_RA2_SetLow();
    </code>

*/
#define IO_RA2_SetLow()           (_LATA2 = 0)
/**
  @Summary
    Toggles the GPIO pin, RA2, using LATA2.

  @Description
    Toggles the GPIO pin, RA2, using LATA2.

  @Preconditions
    The RA2 must be set to an output.

  @Returns
    None.

  @Param
    None.

  @Example
    <code>
    // Toggle RA2
    IO_RA2_Toggle();
    </code>
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

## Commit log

2024-04-13 fixing PICF14 vcc
    [PIC_QuickDevBoard.kicad_pcb, PIC_QuickDevBoard.kicad_sch]
2024-04-13 Updated PCB to REv 2.1 with fix to VCC for PIC16F
    [PIC_QuickDevBoard.kicad_pcb, PIC_QuickDevBoard.kicad_sch]
2024-05-01 Revision 2.2
    [PIC_QuickDevBoard-B_Cu.gbr, PIC_QuickDevBoard-B_Mask.gbr, PIC_QuickDevBoard-B_Paste.gbr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]
2024-05-12 Progressing with calibration code
    [PIC_QuickDevBoard-B_Cu.gbr, PIC_QuickDevBoard-B_Mask.gbr, PIC_QuickDevBoard-B_Paste.gbr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]
2024-05-17 Rev2.3 - fixed mini-usb footprint and pcb routing power from it.
    [PIC_QuickDevBoard.kicad_pcb, PIC_QuickDevBoard.kicad_sch]
2024-05-19 Rev2.3 - led on RB4 and Demo for all three suported PICs
    [PIC_QuickDevBoard.kicad_pcb, PIC_QuickDevBoard.kicad_sch]
2024-05-19 IBOM.HTML Bill of Materials interactive
    [BOM_PIC_QuickDevBoard.csv, PIC_QuickDevBoard.kicad_pcb, PIC_QuickDevBoard.kicad_pcb_bom.csv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]
